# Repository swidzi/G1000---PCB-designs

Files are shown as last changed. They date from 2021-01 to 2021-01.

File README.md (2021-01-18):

# G1000 - PCB-desgins
PCB designes for G1000 Flight Sim controller STL (3d) files made by FlightSimMaker

This repository contains Eagle files for the PCB designed for G1000. All PCBs are millable on single sided clad with a 3018Pro CNC router.
Board design can be changed at anytime.
Boards are designed to be interconnected - if used separately they will probably not work.

# G1000 PFD/MFD PCB interconnection chart

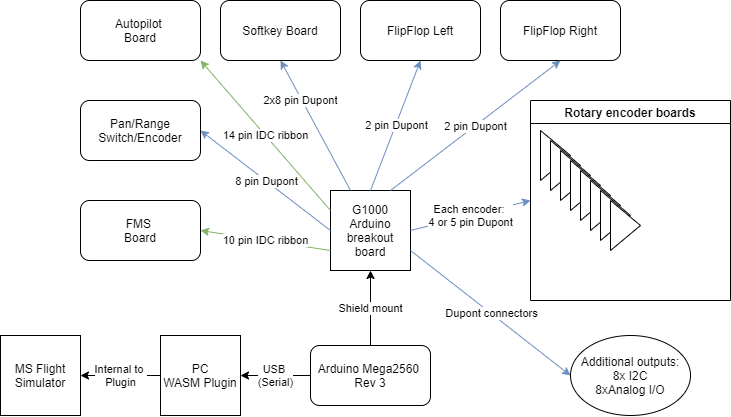
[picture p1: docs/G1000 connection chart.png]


# G1000 Audio PanelPCB interconnection chart

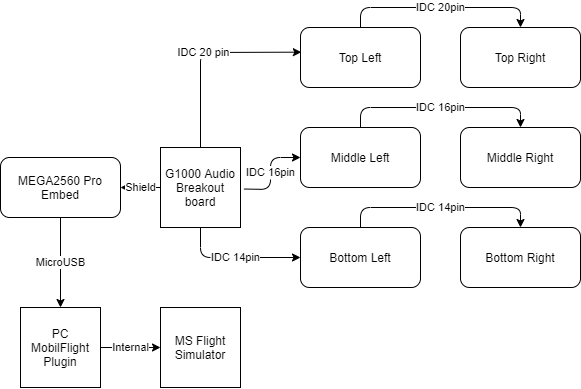
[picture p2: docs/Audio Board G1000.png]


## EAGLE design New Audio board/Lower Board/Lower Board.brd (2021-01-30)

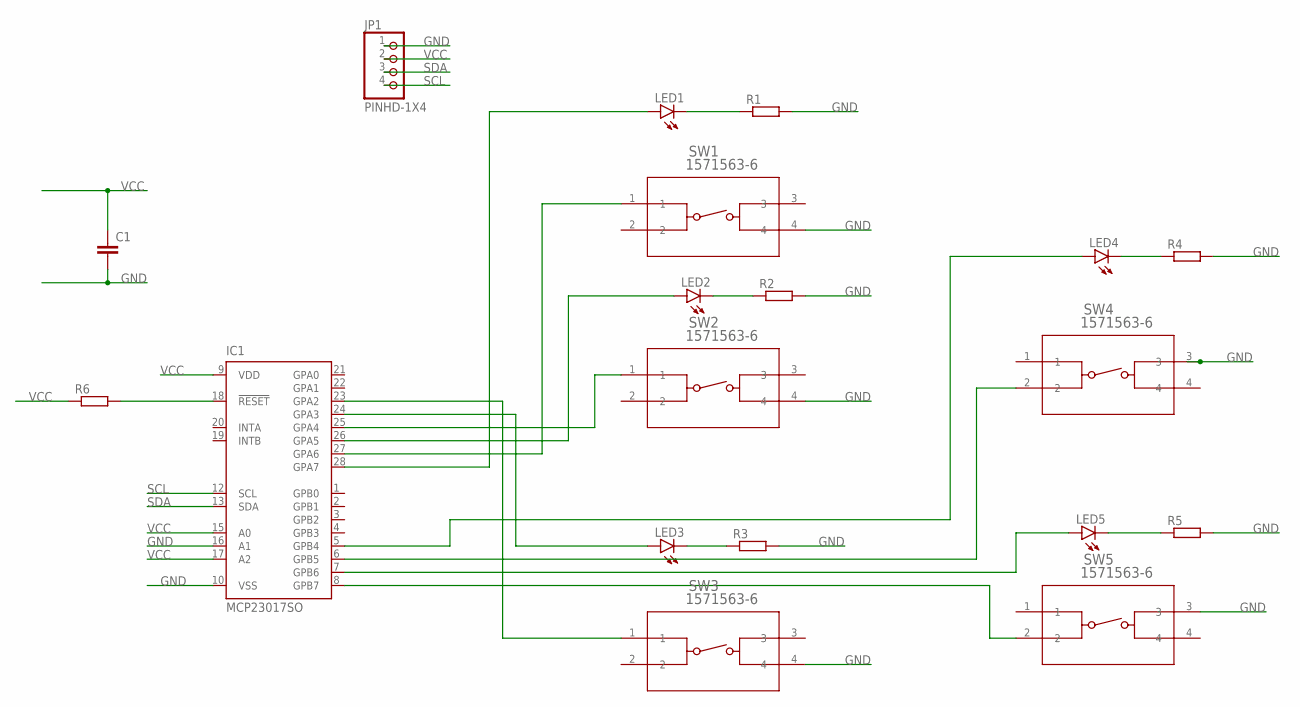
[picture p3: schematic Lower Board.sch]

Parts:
C1: C-EU025-025X050; C025-025X050
IC1: MCP23017SO; SO28W
JP1: PINHD-1X4; 1X04
LED1, LED2, LED3, LED4, LED5: LEDCHIP-LED0805; CHIP-LED0805
R1, R2, R3, R4, R5, R6: R-EU_R0805; R0805
SW1, SW2, SW3, SW4, SW5: 1571563-6; SW4_1437565-E

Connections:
GND: C1.2, IC1.10 (VSS), IC1.16 (A1), JP1.1, R1.2, R2.2, R3.2, R4.2, R5.2, SW1.4, SW2.4, SW3.4, SW4.3, SW5.3
unnamed: LED1.C, R1.1
unnamed: LED2.C, R2.1
unnamed: LED3.C, R3.1
unnamed: LED5.C, R5.1
unnamed: LED4.C, R4.1
unnamed: IC1.28 (GPA7), LED1.A
unnamed: IC1.27 (GPA6), SW1.1
unnamed: IC1.26 (GPA5), LED2.A
unnamed: IC1.25 (GPA4), SW2.1
unnamed: IC1.24 (GPA3), LED3.A
unnamed: IC1.23 (GPA2), SW3.1
unnamed: IC1.8 (GPB7), SW5.2
unnamed: IC1.18 (!RESET), R6.2
unnamed: IC1.7 (GPB6), LED5.A
unnamed: IC1.6 (GPB5), SW4.2
unnamed: IC1.5 (GPB4), LED4.A
SCL: IC1.12 (SCL), JP1.4
SDA: IC1.13 (SDA), JP1.3
VCC: C1.1, IC1.9 (VDD), IC1.15 (A0), IC1.17 (A2), JP1.2, R6.1

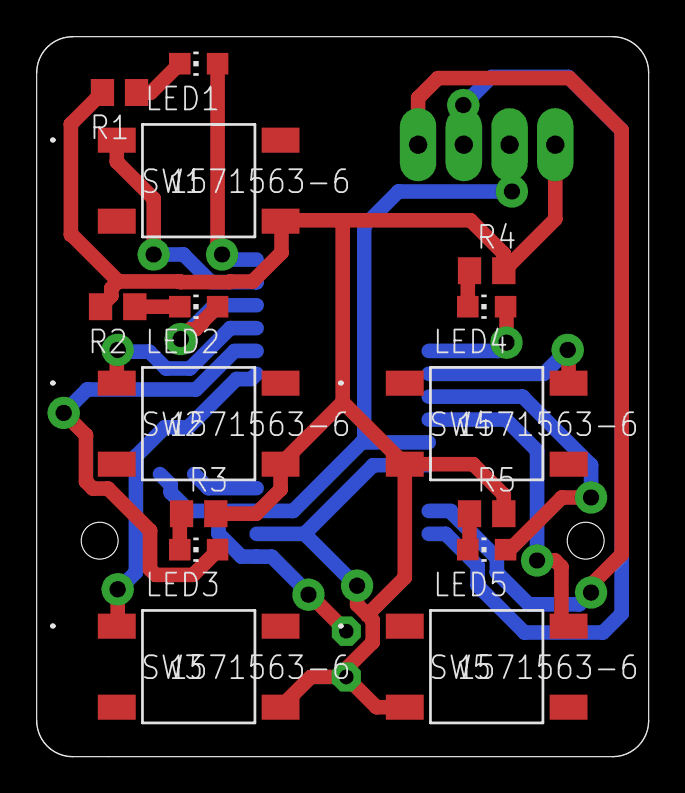
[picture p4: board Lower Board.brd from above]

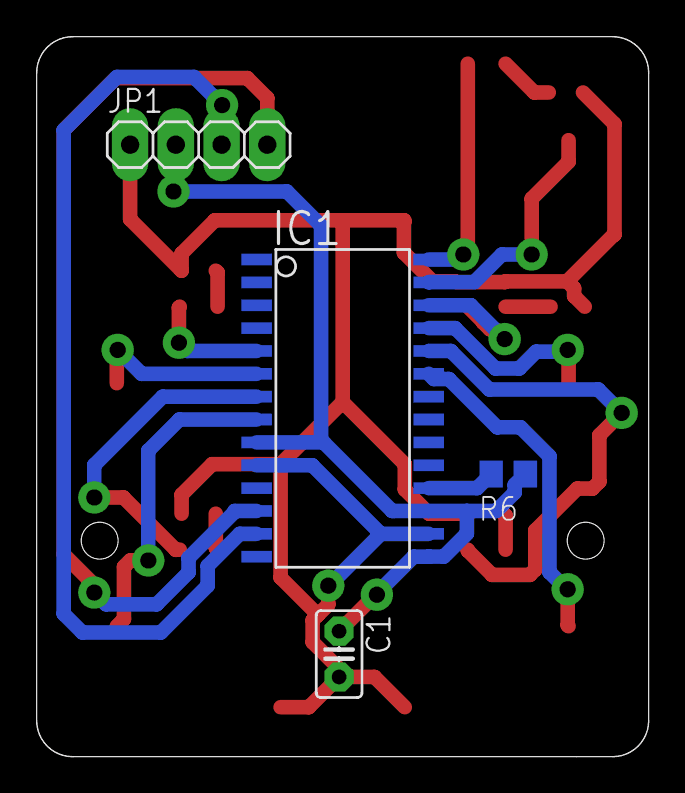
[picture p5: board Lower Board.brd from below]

Board: 2 copper layers, 34.0 x 40.0 mm, 19 parts (4 on the bottom side), 20 nets.

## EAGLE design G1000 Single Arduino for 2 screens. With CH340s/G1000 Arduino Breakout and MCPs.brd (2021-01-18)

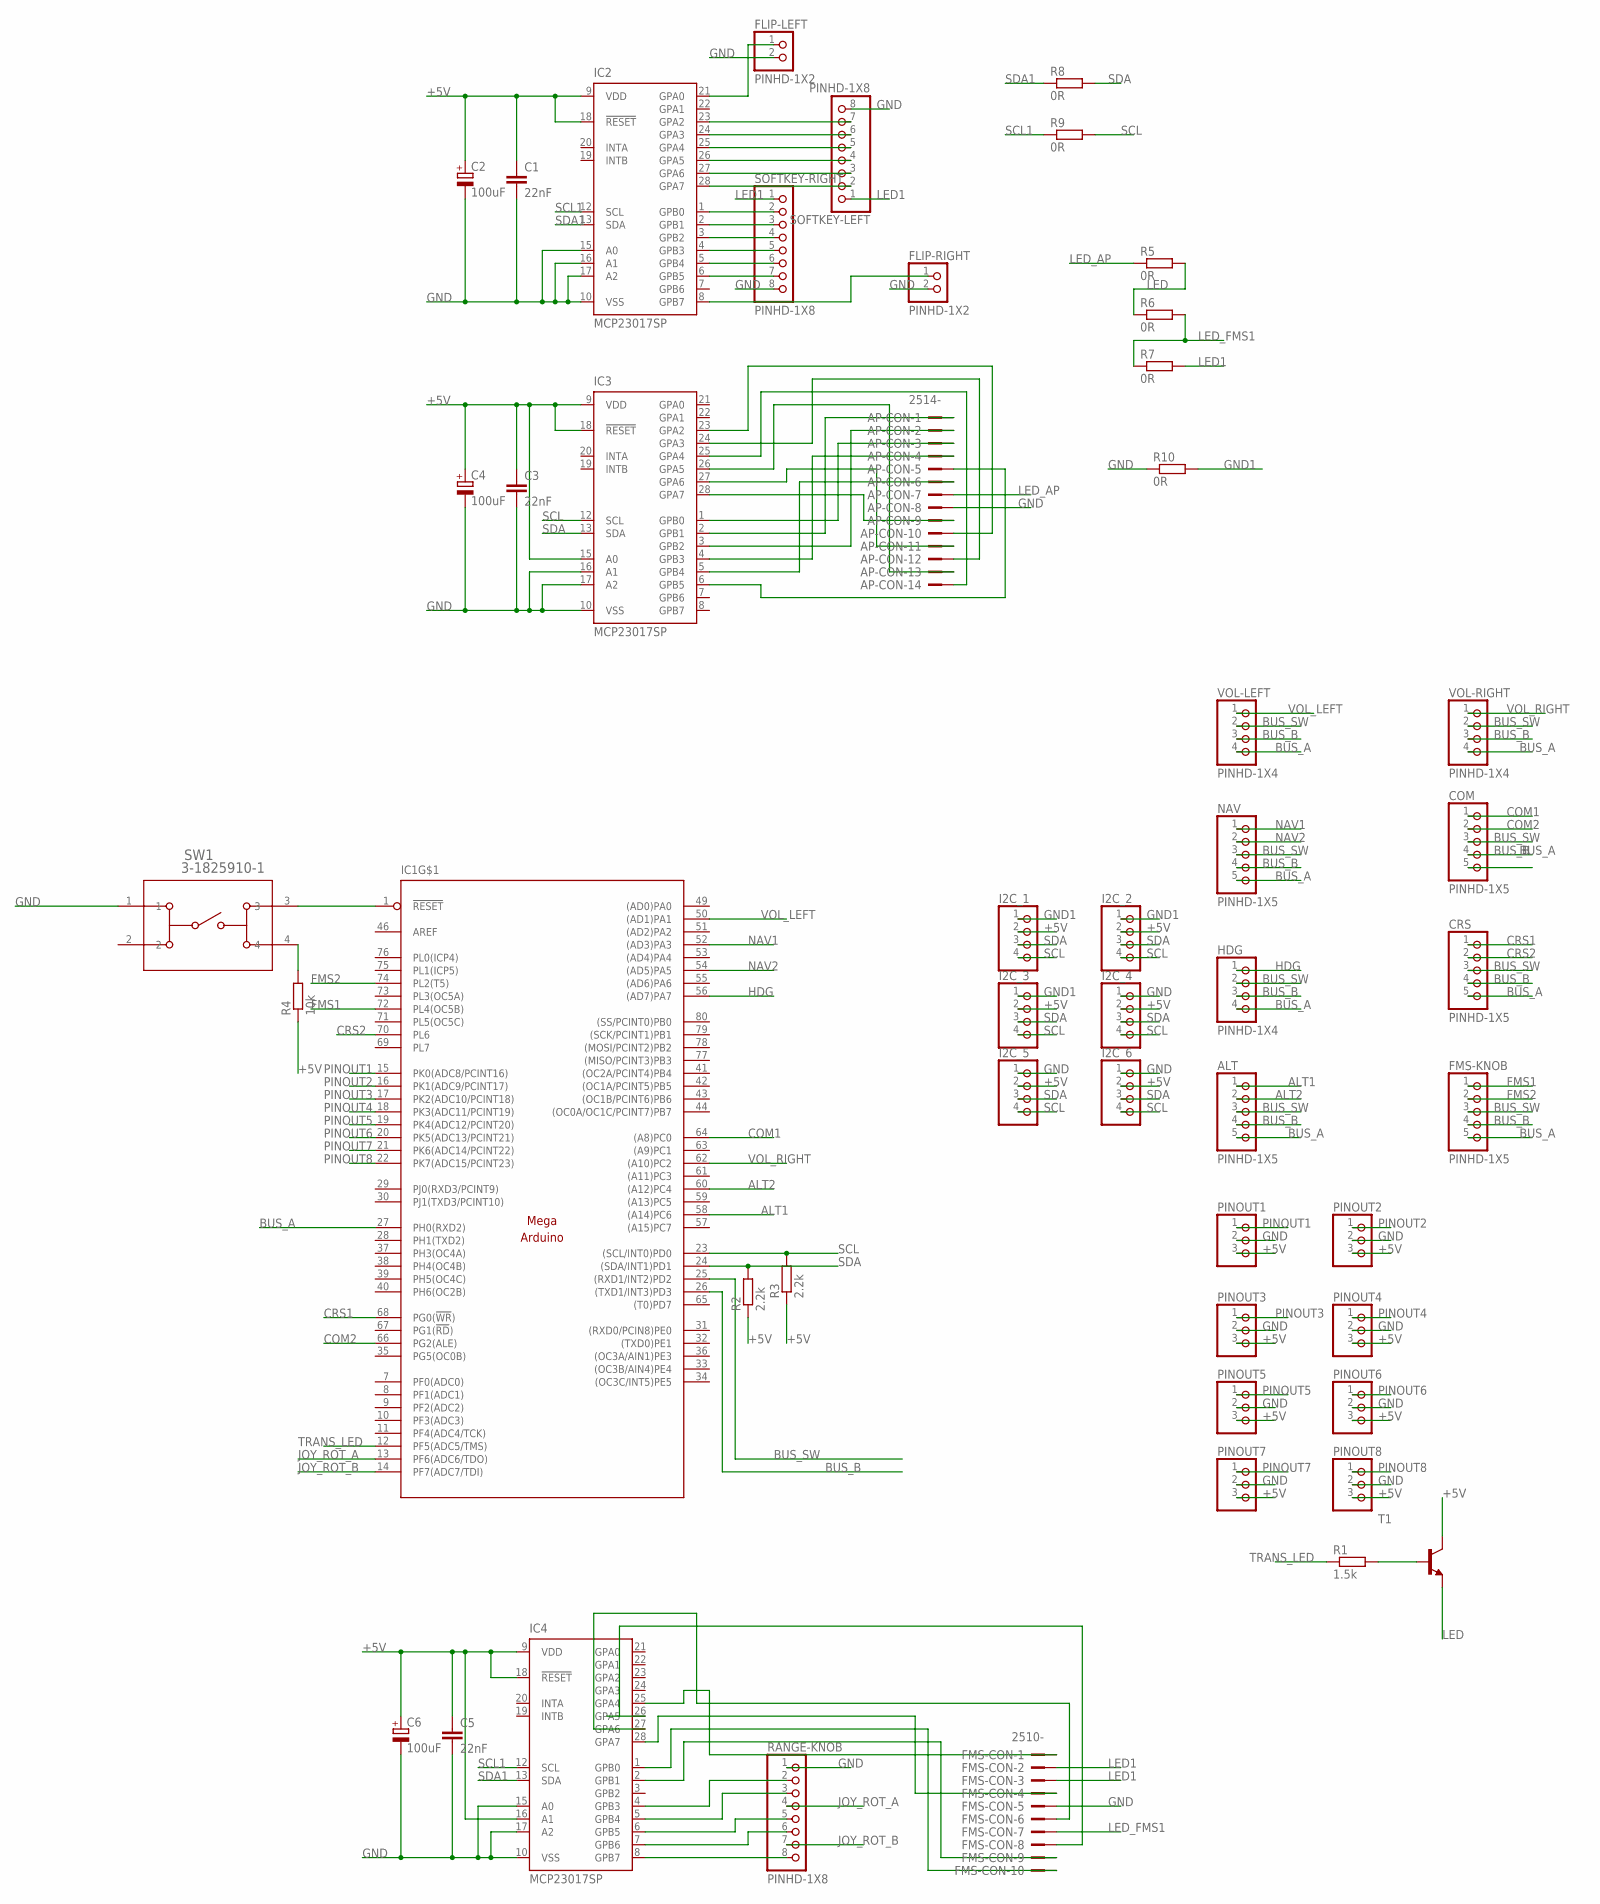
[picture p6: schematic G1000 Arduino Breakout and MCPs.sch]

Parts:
ALT: PINHD-1X5; 1X05
AP-CON: 2514-; PAK100/2500-14
C1, C3, C5: 22nF; C025-025X050
C2, C4, C6: 100uF; E2,5-6
COM: PINHD-1X5; 1X05
CRS: PINHD-1X5; 1X05
FLIP-LEFT: PINHD-1X2; 1X02
FLIP-RIGHT: PINHD-1X2; 1X02
FMS-CON: 2510-; PAK100/2500-10
FMS-KNOB: PINHD-1X5; 1X05
HDG: PINHD-1X4; 1X04
I2C_1, I2C_2, I2C_3, I2C_4, I2C_5, I2C_6: PINHD-1X4; 1X04
IC1: MEGAARDUINO_22; MEGA_ARDUINO_2
IC2, IC3, IC4: MCP23017SP; DIL28-3
NAV: PINHD-1X5; 1X05
PINOUT1, PINOUT2, PINOUT3, PINOUT4, PINOUT5, PINOUT6, PINOUT7, PINOUT8: PINHD-1X3; 1X03
R1: 1.5k; 0207/10
R2, R3: 2.2k; 0207/10
R4: 10k; 0207/10
R5, R6, R7, R8, R9, R10: 0R; 0207/10
RANGE-KNOB: PINHD-1X8; 1X08
SOFTKEY-LEFT: PINHD-1X8; 1X08
SOFTKEY-RIGHT: PINHD-1X8; 1X08
SW1: 3-1825910-1; SW4_1825910-H
T1: 2N2222-NPN-TO92-EBC; TO92-EBC
VOL-LEFT: PINHD-1X4; 1X04
VOL-RIGHT: PINHD-1X4; 1X04

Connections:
+3V3: IC1.2 (+3V3)
+5V: C1.1, C2.+, C3.1, C4.+, C5.1, C6.+, I2C_1.2, I2C_2.2, I2C_3.2, I2C_4.2, I2C_5.2, I2C_6.2, IC1.3 (+5V), IC1.47 (+5V), IC1.48 (+5V), IC2.9 (VDD), IC2.18 (!RESET), IC3.9 (VDD), IC3.15 (A0), IC3.18 (!RESET), IC4.9 (VDD), IC4.16 (A1), IC4.18 (!RESET), PINOUT1.3, PINOUT2.3, PINOUT3.3, PINOUT4.3, PINOUT5.3, PINOUT6.3, PINOUT7.3, PINOUT8.3, R2.1, R3.1, R4.1, T1.C
+VIN: IC1.6 (+VIN)
ALT1: ALT.1, IC1.58 ((A14)PC6)
ALT2: ALT.2, IC1.60 ((A12)PC4)
BUS_A: ALT.5, COM.5, CRS.5, FMS-KNOB.5, HDG.4, IC1.27 (PH0(RXD2)), NAV.5, VOL-LEFT.4, VOL-RIGHT.4
BUS_B: ALT.4, COM.4, CRS.4, FMS-KNOB.4, HDG.3, IC1.26 ((TXD1/INT3)PD3), NAV.4, VOL-LEFT.3, VOL-RIGHT.3
BUS_SW: ALT.3, COM.3, CRS.3, FMS-KNOB.3, HDG.2, IC1.25 ((RXD1/INT2)PD2), NAV.3, VOL-LEFT.2, VOL-RIGHT.2
COM1: COM.1, IC1.64 ((A8)PC0)
COM2: COM.2, IC1.66 (PG2(ALE))
CRS1: CRS.1, IC1.68 (PG0(!WR!))
CRS2: CRS.2, IC1.70 (PL6)
FMS1: FMS-KNOB.1, IC1.72 (PL4(OC5B))
FMS2: FMS-KNOB.2, IC1.74 (PL2(T5))
GND: AP-CON.8, C1.2, C2.-, C3.2, C4.-, C5.2, C6.-, FLIP-LEFT.2, FLIP-RIGHT.2, FMS-CON.5, I2C_4.1, I2C_5.1, I2C_6.1, IC1.4 (GND), IC1.5 (GND), IC1.45 (GND), IC1.81 (GND), IC1.82 (GND), IC2.10 (VSS), IC2.15 (A0), IC2.16 (A1), IC2.17 (A2), IC3.10 (VSS), IC3.16 (A1), IC3.17 (A2), IC4.10 (VSS), IC4.15 (A0), IC4.17 (A2), PINOUT1.2, PINOUT2.2, PINOUT3.2, PINOUT4.2, PINOUT5.2, PINOUT6.2, PINOUT7.2, PINOUT8.2, R10.1, RANGE-KNOB.1, SOFTKEY-LEFT.8, SOFTKEY-RIGHT.8, SW1.1
GND1: I2C_1.1, I2C_2.1, I2C_3.1, R10.2
HDG: HDG.1, IC1.56 ((AD7)PA7)
JOY_ROT_A: IC1.13 (PF6(ADC6/TDO)), RANGE-KNOB.4
JOY_ROT_B: IC1.14 (PF7(ADC7/TDI)), RANGE-KNOB.7
LED: R5.2, R6.1, T1.E
LED1: FMS-CON.2, FMS-CON.3, R7.2, SOFTKEY-LEFT.1, SOFTKEY-RIGHT.1
LED_AP: AP-CON.7, R5.1
LED_FMS1: FMS-CON.7, R6.2, R7.1
unnamed: R1.2, T1.B
unnamed: IC2.1 (GPB0), SOFTKEY-RIGHT.2
unnamed: IC2.2 (GPB1), SOFTKEY-RIGHT.3
unnamed: IC2.3 (GPB2), SOFTKEY-RIGHT.4
unnamed: IC2.4 (GPB3), SOFTKEY-RIGHT.5
unnamed: IC2.5 (GPB4), SOFTKEY-RIGHT.6
unnamed: IC2.6 (GPB5), SOFTKEY-RIGHT.7
unnamed: IC2.28 (GPA7), SOFTKEY-LEFT.2
unnamed: IC2.27 (GPA6), SOFTKEY-LEFT.3
unnamed: IC2.26 (GPA5), SOFTKEY-LEFT.4
unnamed: IC2.25 (GPA4), SOFTKEY-LEFT.5
unnamed: IC2.24 (GPA3), SOFTKEY-LEFT.6
unnamed: IC2.23 (GPA2), SOFTKEY-LEFT.7
unnamed: FLIP-LEFT.1, IC2.21 (GPA0)
unnamed: FLIP-RIGHT.1, IC2.8 (GPB7)
unnamed: R4.2, SW1.4
unnamed: AP-CON.3, IC3.1 (GPB0)
unnamed: IC1.1 (!RESET), SW1.3
unnamed: AP-CON.1, IC3.2 (GPB1)
unnamed: AP-CON.2, IC3.3 (GPB2)
unnamed: AP-CON.4, IC3.4 (GPB3)
unnamed: AP-CON.6, IC3.5 (GPB4)
unnamed: AP-CON.9, IC3.28 (GPA7)
unnamed: AP-CON.11, IC3.27 (GPA6)
unnamed: AP-CON.13, IC3.26 (GPA5)
unnamed: AP-CON.14, IC3.25 (GPA4)
unnamed: AP-CON.12, IC3.24 (GPA3)
unnamed: AP-CON.10, IC3.23 (GPA2)
unnamed: AP-CON.5, IC3.6 (GPB5)
unnamed: IC4.8 (GPB7), RANGE-KNOB.8
unnamed: IC4.7 (GPB6), RANGE-KNOB.6
unnamed: IC4.6 (GPB5), RANGE-KNOB.5
unnamed: IC4.5 (GPB4), RANGE-KNOB.3
unnamed: IC4.4 (GPB3), RANGE-KNOB.2
unnamed: FMS-CON.1, IC4.25 (GPA4)
unnamed: FMS-CON.9, IC4.2 (GPB1)
unnamed: FMS-CON.10, IC4.1 (GPB0)
unnamed: FMS-CON.4, IC4.28 (GPA7)
unnamed: FMS-CON.6, IC4.27 (GPA6)
unnamed: FMS-CON.8, IC4.26 (GPA5)
NAV1: IC1.52 ((AD3)PA3), NAV.1
NAV2: IC1.54 ((AD5)PA5), NAV.2
PINOUT1: IC1.15 (PK0(ADC8/PCINT16)), PINOUT1.1
PINOUT2: IC1.16 (PK1(ADC9/PCINT17)), PINOUT2.1
PINOUT3: IC1.17 (PK2(ADC10/PCINT18)), PINOUT3.1
PINOUT4: IC1.18 (PK3(ADC11/PCINT19)), PINOUT4.1
PINOUT5: IC1.19 (PK4(ADC12/PCINT20)), PINOUT5.1
PINOUT6: IC1.20 (PK5(ADC13/PCINT21)), PINOUT6.1
PINOUT7: IC1.21 (PK6(ADC14/PCINT22)), PINOUT7.1
PINOUT8: IC1.22 (PK7(ADC15/PCINT23)), PINOUT8.1
SCL: I2C_1.4, I2C_2.4, I2C_3.4, I2C_4.4, I2C_5.4, I2C_6.4, IC1.23 ((SCL/INT0)PD0), IC3.12 (SCL), R3.2, R9.2
SCL1: IC2.12 (SCL), IC4.12 (SCL), R9.1
SDA: I2C_1.3, I2C_2.3, I2C_3.3, I2C_4.3, I2C_5.3, I2C_6.3, IC1.24 ((SDA/INT1)PD1), IC3.13 (SDA), R2.2, R8.2
SDA1: IC2.13 (SDA), IC4.13 (SDA), R8.1
TRANS_LED: IC1.12 (PF5(ADC5/TMS)), R1.1
VOL_LEFT: IC1.50 ((AD1)PA1), VOL-LEFT.1
VOL_RIGHT: IC1.62 ((A10)PC2), VOL-RIGHT.1

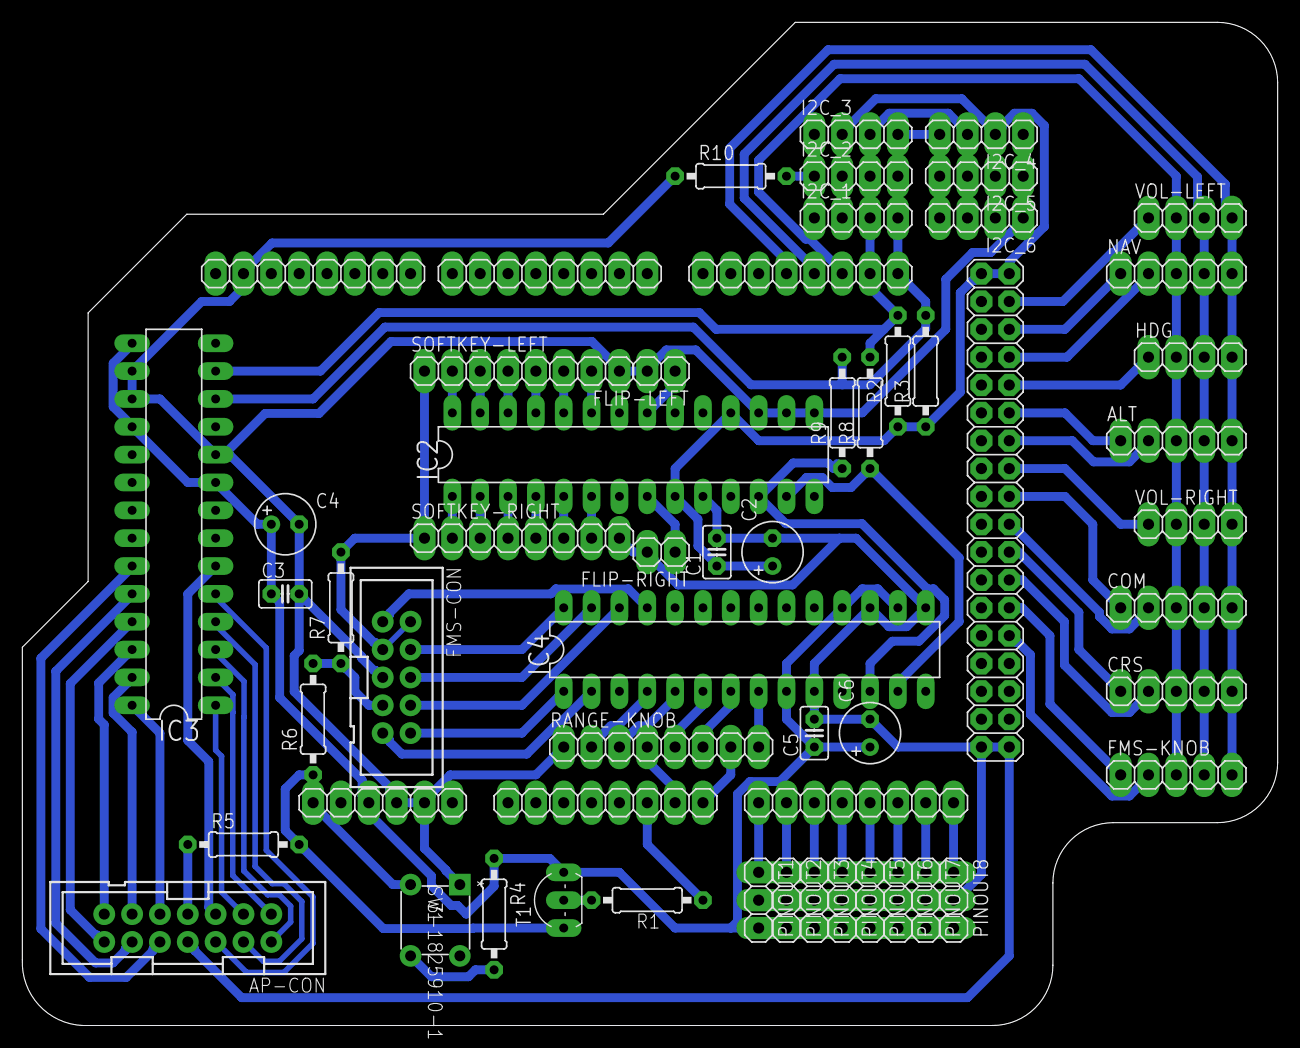
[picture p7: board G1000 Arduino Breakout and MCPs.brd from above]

Board: 2 copper layers, 114.5 x 91.5 mm, 51 parts (0 on the bottom side), 78 nets.

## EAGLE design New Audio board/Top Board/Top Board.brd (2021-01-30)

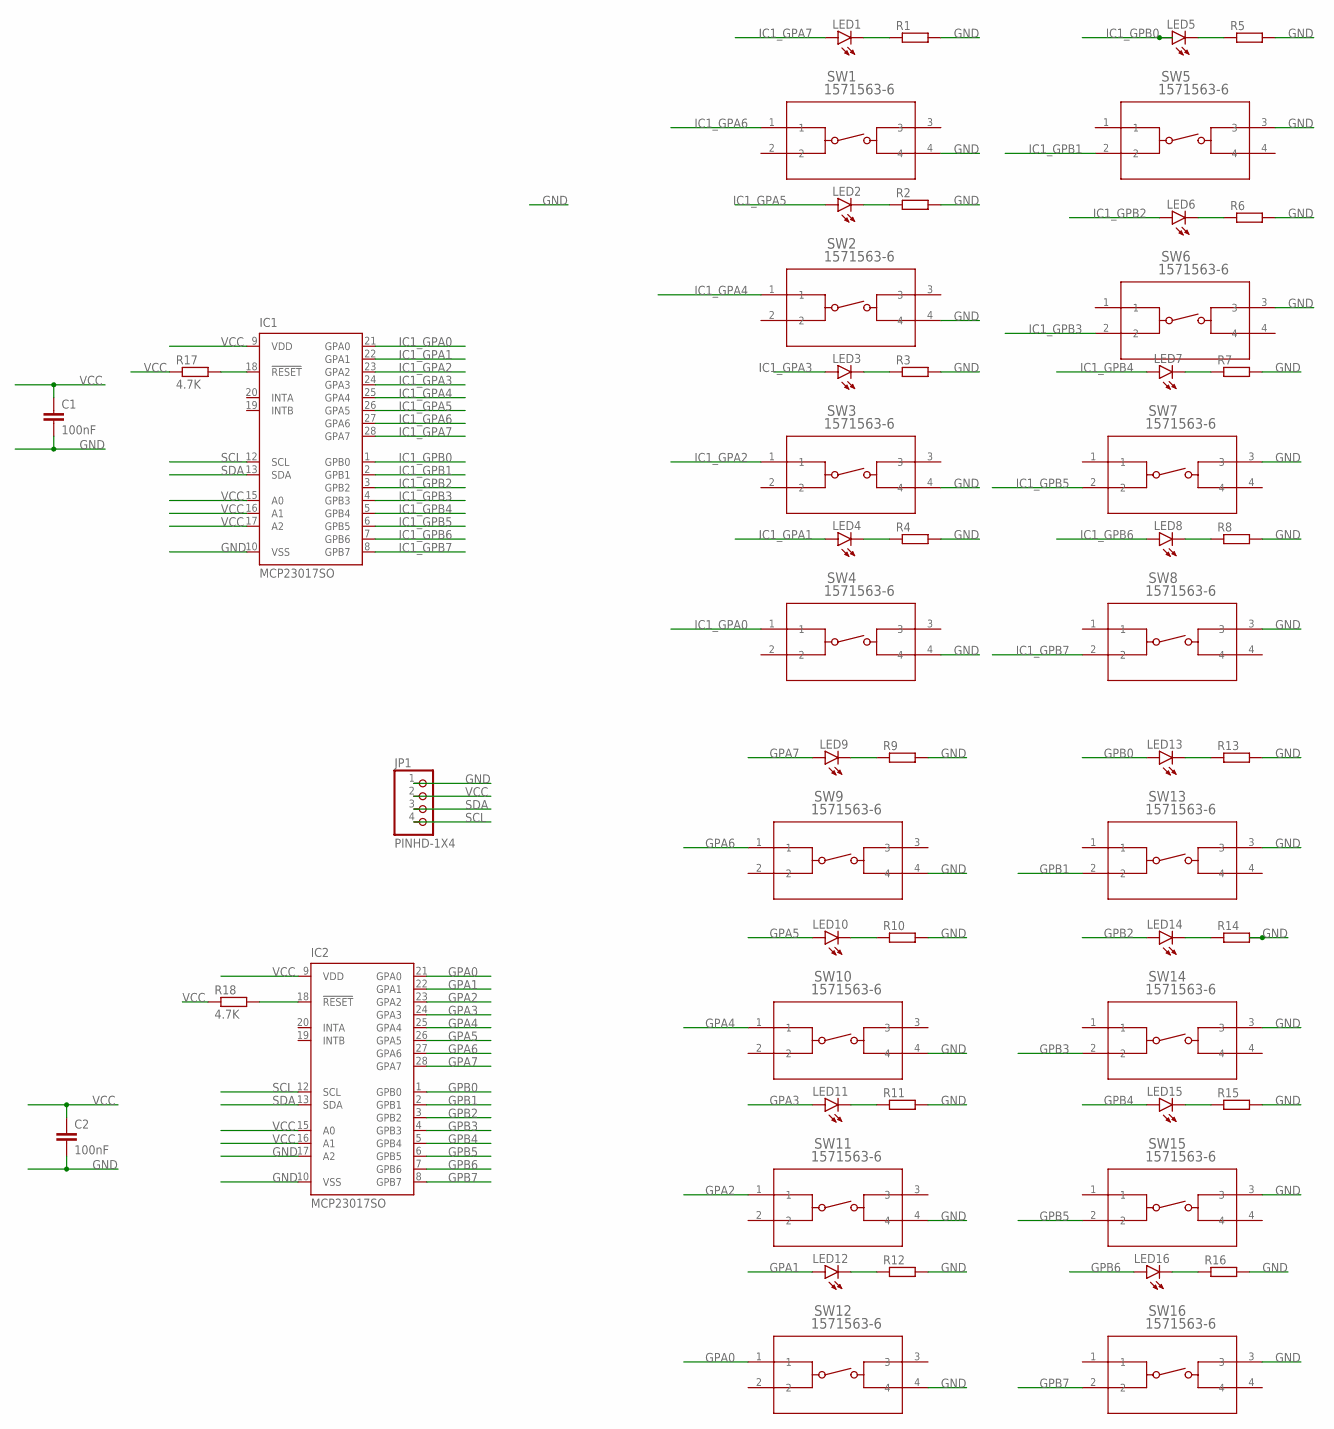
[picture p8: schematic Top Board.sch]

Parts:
C1, C2: 100nF; C025-025X050
IC1, IC2: MCP23017SO; SO28W
JP1: PINHD-1X4; 1X04
LED1, LED2, LED3, LED4, LED5, LED6, LED7, LED8, LED9, LED10, LED11, LED12, LED13, LED14, LED15, LED16: LEDCHIP-LED0805; CHIP-LED0805
R1, R2, R3, R4, R5, R6, R7, R8, R9, R10, R11, R12, R13, R14, R15, R16: R-EU_R0805; R0805
R17, R18: 4.7K; R0805
SW1, SW2, SW3, SW4, SW5, SW6, SW7, SW8, SW9, SW10, SW11, SW12, SW13, SW14, SW15, SW16: 1571563-6; SW4_1437565-E

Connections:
GND: C1.2, C2.2, IC1.10 (VSS), IC2.10 (VSS), IC2.17 (A2), JP1.1, R1.2, R2.2, R3.2, R4.2, R5.2, R6.2, R7.2, R8.2, R9.2, R10.2, R11.2, R12.2, R13.2, R14.2, R15.2, R16.2, SW1.4, SW2.4, SW3.4, SW4.4, SW5.3, SW6.3, SW7.3, SW8.3, SW9.4, SW10.4, SW11.4, SW12.4, SW13.3, SW14.3, SW15.3, SW16.3
GPA0: IC2.21 (GPA0), SW12.1
GPA1: IC2.22 (GPA1), LED12.A
GPA2: IC2.23 (GPA2), SW11.1
GPA3: IC2.24 (GPA3), LED11.A
GPA4: IC2.25 (GPA4), SW10.1
GPA5: IC2.26 (GPA5), LED10.A
GPA6: IC2.27 (GPA6), SW9.1
GPA7: IC2.28 (GPA7), LED9.A
GPB0: IC2.1 (GPB0), LED13.A
GPB1: IC2.2 (GPB1), SW13.2
GPB2: IC2.3 (GPB2), LED14.A
GPB3: IC2.4 (GPB3), SW14.2
GPB4: IC2.5 (GPB4), LED15.A
GPB5: IC2.6 (GPB5), SW15.2
GPB6: IC2.7 (GPB6), LED16.A
GPB7: IC2.8 (GPB7), SW16.2
IC1_GPA0: IC1.21 (GPA0), SW4.1
IC1_GPA1: IC1.22 (GPA1), LED4.A
IC1_GPA2: IC1.23 (GPA2), SW3.1
IC1_GPA3: IC1.24 (GPA3), LED3.A
IC1_GPA4: IC1.25 (GPA4), SW2.1
IC1_GPA5: IC1.26 (GPA5), LED2.A
IC1_GPA6: IC1.27 (GPA6), SW1.1
IC1_GPA7: IC1.28 (GPA7), LED1.A
IC1_GPB0: IC1.1 (GPB0), LED5.A
IC1_GPB1: IC1.2 (GPB1), SW5.2
IC1_GPB2: IC1.3 (GPB2), LED6.A
IC1_GPB3: IC1.4 (GPB3), SW6.2
IC1_GPB4: IC1.5 (GPB4), LED7.A
IC1_GPB5: IC1.6 (GPB5), SW7.2
IC1_GPB6: IC1.7 (GPB6), LED8.A
IC1_GPB7: IC1.8 (GPB7), SW8.2
unnamed: LED1.C, R1.1
unnamed: LED2.C, R2.1
unnamed: LED3.C, R3.1
unnamed: LED4.C, R4.1
unnamed: LED5.C, R5.1
unnamed: LED6.C, R6.1
unnamed: LED7.C, R7.1
unnamed: LED8.C, R8.1
unnamed: LED9.C, R9.1
unnamed: LED10.C, R10.1
unnamed: LED11.C, R11.1
unnamed: LED12.C, R12.1
unnamed: LED13.C, R13.1
unnamed: LED14.C, R14.1
unnamed: LED15.C, R15.1
unnamed: LED16.C, R16.1
unnamed: IC2.18 (!RESET), R18.2
unnamed: IC1.18 (!RESET), R17.2
SCL: IC1.12 (SCL), IC2.12 (SCL), JP1.4
SDA: IC1.13 (SDA), IC2.13 (SDA), JP1.3
VCC: C1.1, C2.1, IC1.9 (VDD), IC1.15 (A0), IC1.16 (A1), IC1.17 (A2), IC2.9 (VDD), IC2.15 (A0), IC2.16 (A1), JP1.2, R17.1, R18.1

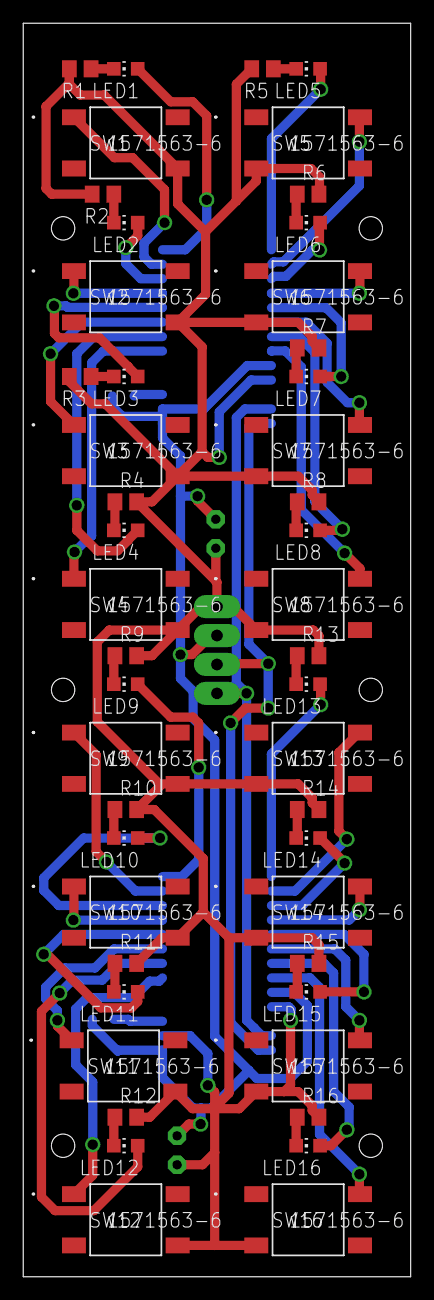
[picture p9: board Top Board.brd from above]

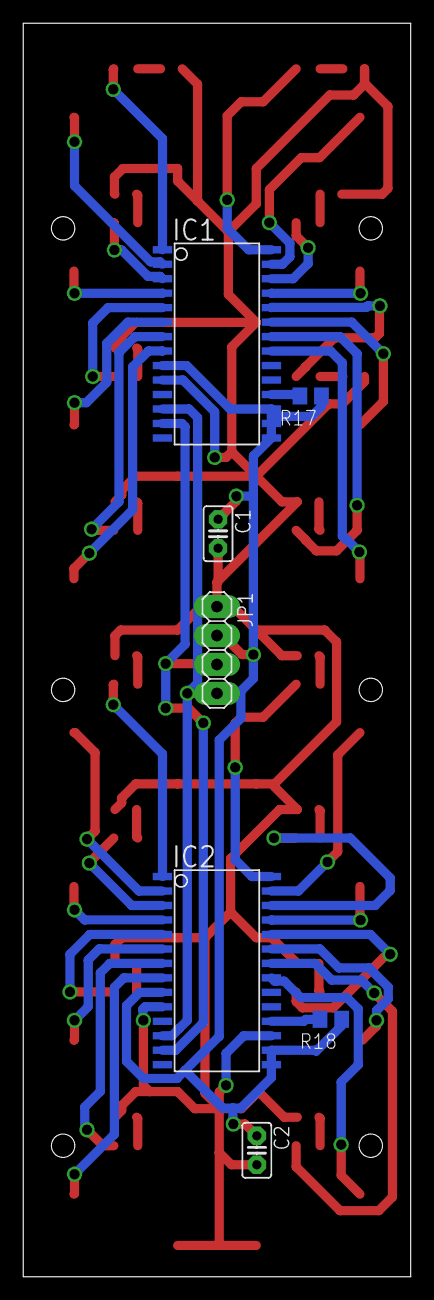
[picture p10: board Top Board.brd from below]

Board: 2 copper layers, 34.0 x 110.0 mm, 55 parts (7 on the bottom side), 54 nets.

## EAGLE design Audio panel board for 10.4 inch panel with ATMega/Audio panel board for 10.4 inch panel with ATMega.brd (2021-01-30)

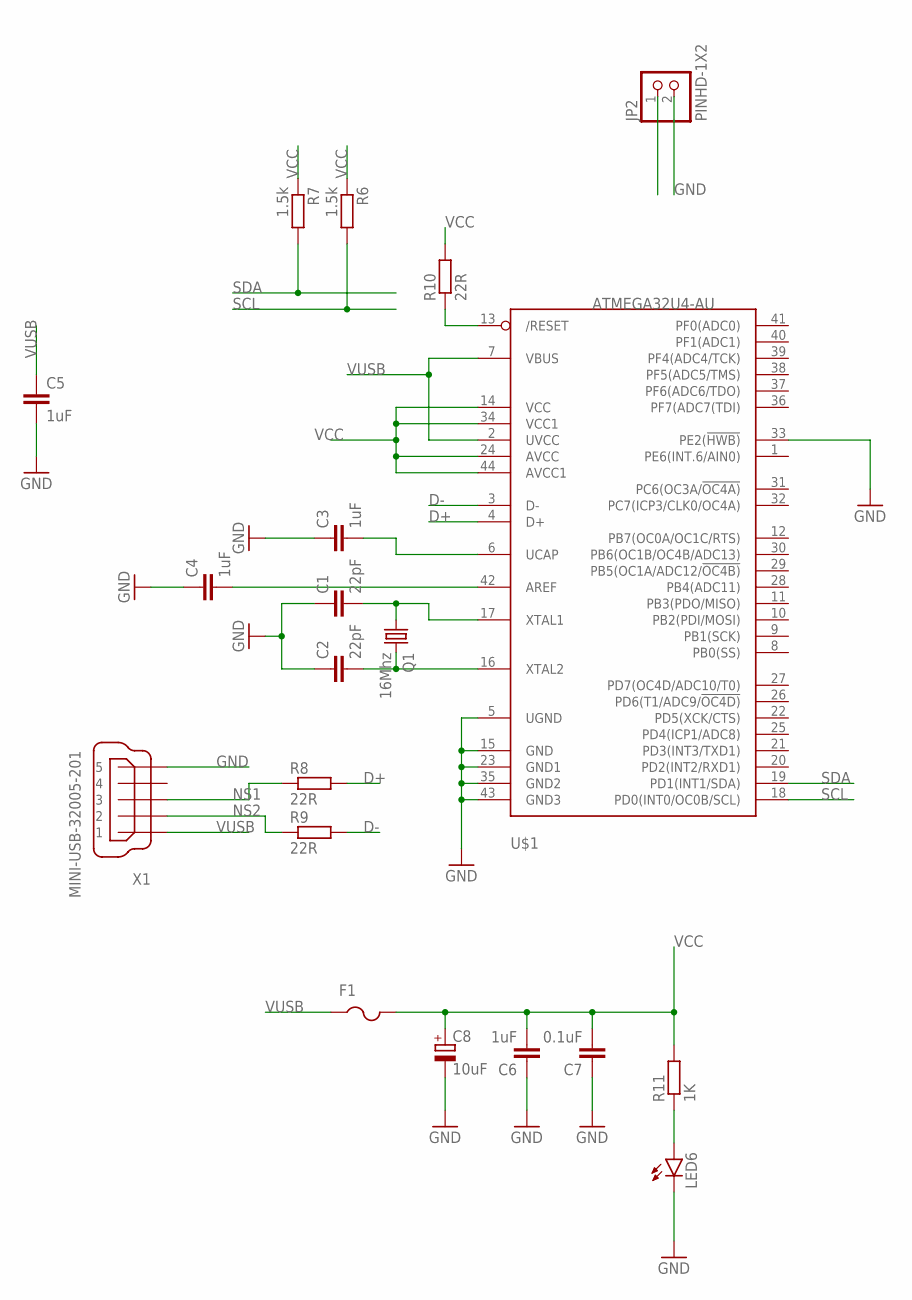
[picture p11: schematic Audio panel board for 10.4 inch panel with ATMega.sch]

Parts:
C1, C2: 22pF; C025-025X050
C3, C4, C5, C6: 1uF; C025-025X050
C7: 0.1uF; C025-025X050
C8: 10uF; E2,5-7
F1: PTCFUSE-1206; R1206
JP2: PINHD-1X2; 1X02
LED6: LEDCHIP-LED0805; CHIP-LED0805
Q1: 16Mhz; HC49/S
R6, R7: 1.5k; R0805
R8, R9, R10: 22R; R0805
R11: 1K; R0805
U$1: ATMEGA32U4-AU; TQFP44
X1: MINI-USB-32005-201; 32005-201

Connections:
D+: R8.2, U$1.4 (D+)
D-: R9.2, U$1.3 (D-)
GND: C1.1, C2.1, C3.1, C4.1, C5.2, C6.1, C7.1, C8.-, JP2.2, LED6.C, U$1.5 (UGND), U$1.15 (GND), U$1.23 (GND1), U$1.33 (PE2(!HWB)), U$1.35 (GND2), U$1.43 (GND3), X1.5
unnamed: C4.2, U$1.42 (AREF)
unnamed: C2.2, Q1.2, U$1.16 (XTAL2)
unnamed: C1.2, Q1.1, U$1.17 (XTAL1)
unnamed: C3.2, U$1.6 (UCAP)
unnamed: R10.1, U$1.13 (/RESET)
unnamed: LED6.A, R11.1
NS1: R8.1, X1.3
NS2: R9.1, X1.2
SCL: R6.2, U$1.18 (PD0(INT0/OC0B/SCL))
SDA: R7.2, U$1.19 (PD1(INT1/SDA))
VCC: C6.2, C7.2, C8.+, F1.2, R6.1, R7.1, R10.2, R11.2, U$1.14 (VCC), U$1.24 (AVCC), U$1.34 (VCC1), U$1.44 (AVCC1)
VUSB: C5.1, F1.1, U$1.2 (UVCC), U$1.7 (VBUS), X1.1

Board: 2 copper layers, 20 parts (1 on the bottom side), 15 nets, no tracks yet.

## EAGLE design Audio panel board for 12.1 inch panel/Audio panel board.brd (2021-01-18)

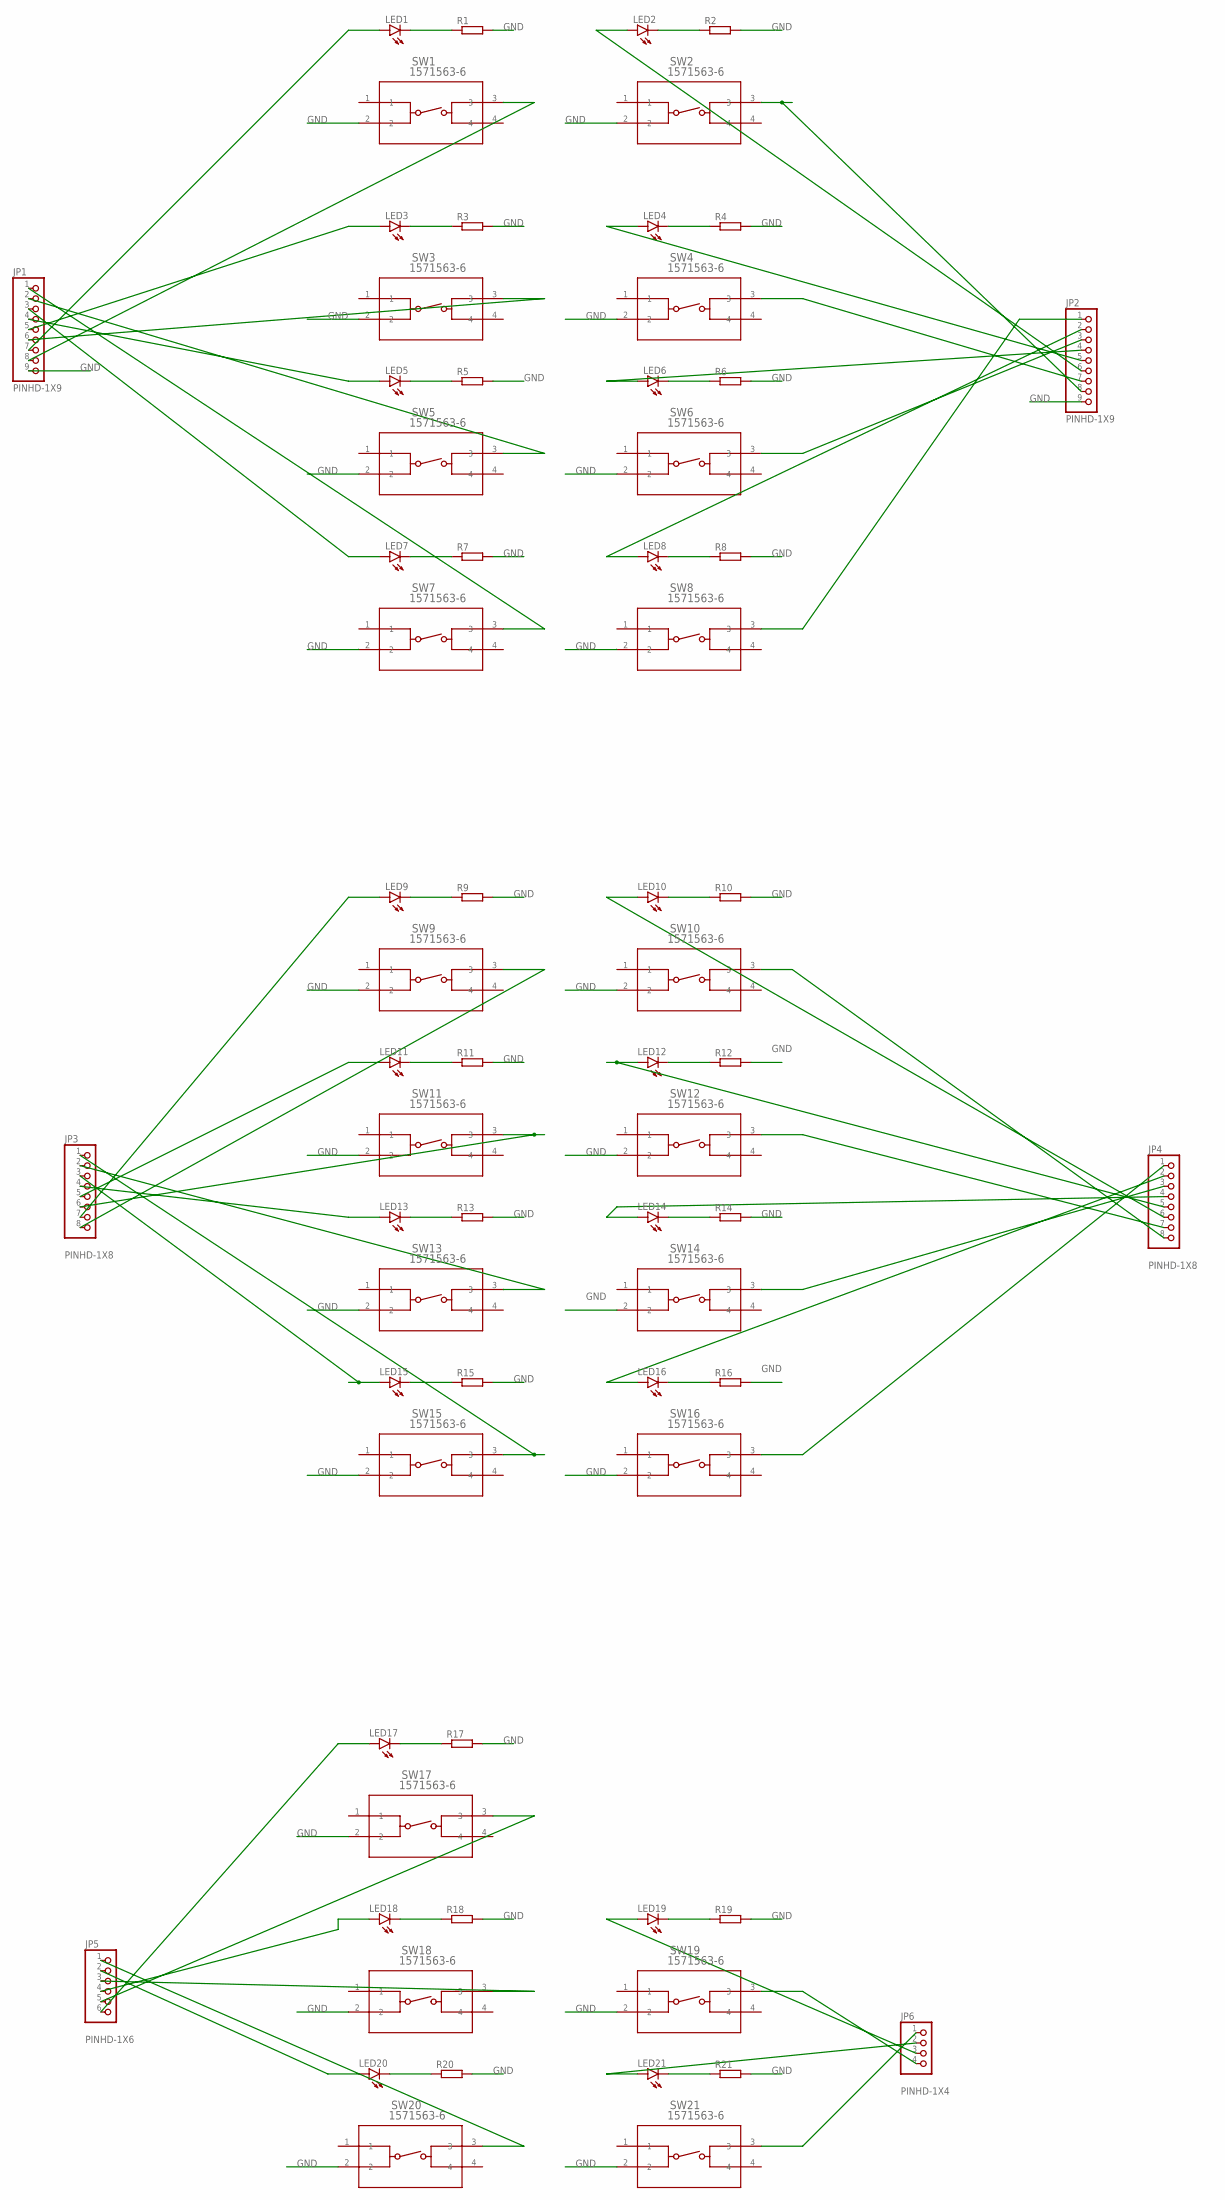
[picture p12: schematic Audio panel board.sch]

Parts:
JP1, JP2: PINHD-1X9; 1X09
JP3, JP4: PINHD-1X8; 1X08
JP5: PINHD-1X6; 1X06
JP6: PINHD-1X4; 1X04
LED1, LED2, LED3, LED4, LED5, LED6, LED7, LED8, LED9, LED10, LED11, LED12, LED13, LED14, LED15, LED16, LED17, LED18, LED19, LED20, LED21: LEDCHIP-LED0805; CHIP-LED0805
R1, R2, R3, R4, R5, R6, R7, R8, R9, R10, R11, R12, R13, R14, R15, R16, R17, R18, R19, R20, R21: R-EU_R1206; R1206
SW1, SW2, SW3, SW4, SW5, SW6, SW7, SW8, SW9, SW10, SW11, SW12, SW13, SW14, SW15, SW16, SW17, SW18, SW19, SW20, SW21: 1571563-6; SW4_1437565-E

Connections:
GND: JP1.9, JP2.9, R1.2, R2.2, R3.2, R4.2, R5.2, R6.2, R7.2, R8.2, R9.2, R10.2, R11.2, R12.2, R13.2, R14.2, R15.2, R16.2, R17.2, R18.2, R19.2, R20.2, R21.2, SW1.2, SW2.2, SW3.2, SW4.2, SW5.2, SW6.2, SW7.2, SW8.2, SW9.2, SW10.2, SW11.2, SW12.2, SW13.2, SW14.2, SW15.2, SW16.2, SW17.2, SW18.2, SW19.2, SW20.2, SW21.2
unnamed: JP2.1, SW8.3
unnamed: JP4.8, SW10.3
unnamed: JP5.4, LED18.A
unnamed: LED1.C, R1.1
unnamed: LED2.C, R2.1
unnamed: LED3.C, R3.1
unnamed: JP1.7, LED1.A
unnamed: JP1.5, LED3.A
unnamed: JP2.6, LED2.A
unnamed: JP2.8, SW2.3
unnamed: JP1.8, SW1.3
unnamed: JP1.6, SW3.3
unnamed: LED4.C, R4.1
unnamed: JP2.5, LED4.A
unnamed: JP2.7, SW4.3
unnamed: LED5.C, R5.1
unnamed: JP1.4, LED5.A
unnamed: JP1.2, SW5.3
unnamed: LED6.C, R6.1
unnamed: JP2.4, LED6.A
unnamed: JP2.3, SW6.3
unnamed: LED7.C, R7.1
unnamed: JP1.3, LED7.A
unnamed: JP1.1, SW7.3
unnamed: LED8.C, R8.1
unnamed: JP2.2, LED8.A
unnamed: LED9.C, R9.1
unnamed: JP3.7, LED9.A
unnamed: JP3.8, SW9.3
unnamed: LED10.C, R10.1
unnamed: JP4.6, LED10.A
unnamed: LED11.C, R11.1
unnamed: JP3.5, LED11.A
unnamed: JP3.6, SW11.3
unnamed: LED12.C, R12.1
unnamed: JP4.5, LED12.A
unnamed: JP4.7, SW12.3
unnamed: LED13.C, R13.1
unnamed: JP3.4, LED13.A
unnamed: JP3.2, SW13.3
unnamed: LED14.C, R14.1
unnamed: JP4.4, LED14.A
unnamed: JP4.3, SW14.3
unnamed: LED15.C, R15.1
unnamed: JP3.3, LED15.A
unnamed: JP3.1, SW15.3
unnamed: LED16.C, R16.1
unnamed: JP4.2, LED16.A
unnamed: JP4.1, SW16.3
unnamed: LED17.C, R17.1
unnamed: JP5.6, LED17.A
unnamed: JP5.5, SW17.3
unnamed: LED18.C, R18.1
unnamed: JP5.3, SW18.3
unnamed: LED19.C, R19.1
unnamed: JP6.3, LED19.A
unnamed: JP6.4, SW19.3
unnamed: LED20.C, R20.1
unnamed: JP5.2, LED20.A
unnamed: JP5.1, SW20.3
unnamed: LED21.C, R21.1
unnamed: JP6.2, LED21.A
unnamed: JP6.1, SW21.3

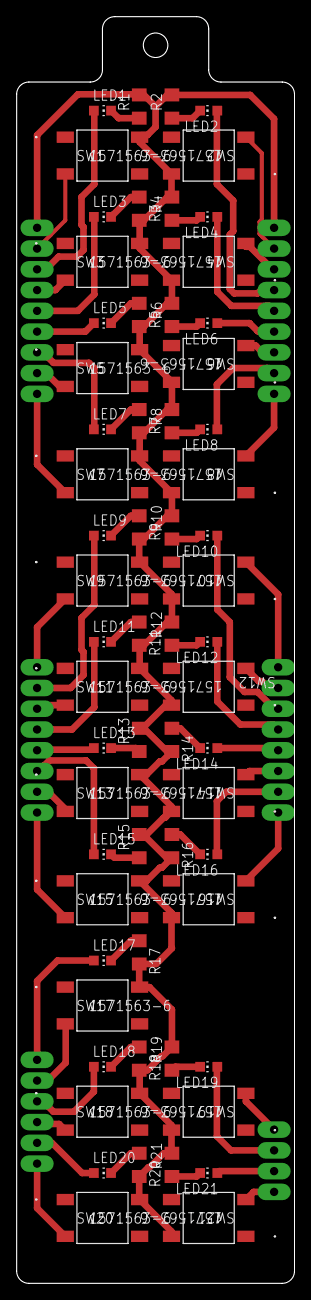
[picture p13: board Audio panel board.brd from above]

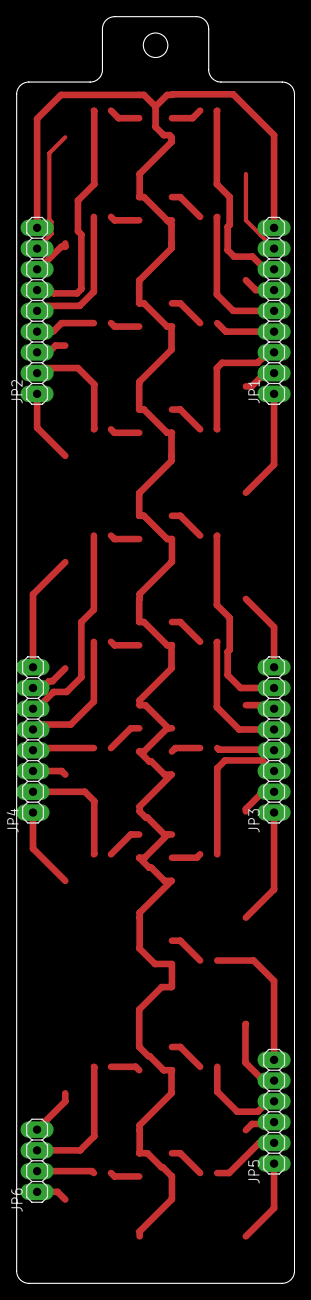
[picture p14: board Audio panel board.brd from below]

Board: 2 copper layers, 34.0 x 155.0 mm, 69 parts (6 on the bottom side), 64 nets.

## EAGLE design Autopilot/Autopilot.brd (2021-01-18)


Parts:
LED1, LED2, LED3, LED4, LED5, LED6: LEDCHIPLED_1206; CHIPLED_1206
R1, R2, R3, R4, R5, R6: R-EU_R1206; R1206
SW1, SW2, SW3, SW4, SW5, SW6, SW7, SW8, SW9, SW10, SW11, SW12: 1571563-6; SW4_1437565-E
X1: 2514-; PAK100/2500-14

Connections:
5V: LED1.A, LED2.A, LED3.A, LED4.A, LED5.A, LED6.A, X1.7
GND: R1.1, R2.1, R3.1, R4.1, R5.1, R6.1, SW1.4, SW2.2, SW3.2, SW4.2, SW5.2, SW6.2, SW7.4, SW8.2, SW9.2, SW10.2, SW11.2, SW12.2, X1.8
unnamed: LED1.C, R1.2
unnamed: LED2.C, R2.2
unnamed: LED3.C, R3.2
unnamed: LED4.C, R4.2
unnamed: LED5.C, R5.2
unnamed: LED6.C, R6.2
unnamed: SW1.2, X1.9
unnamed: SW7.1, X1.5
unnamed: SW8.3, X1.3
unnamed: SW9.3, X1.1
unnamed: SW10.3, X1.2
unnamed: SW11.3, X1.4
unnamed: SW12.3, X1.6
unnamed: SW2.4, X1.11
unnamed: SW4.4, X1.14
unnamed: SW3.4, X1.13
unnamed: SW5.4, X1.12
unnamed: SW6.4, X1.10


Board: 2 copper layers, 34.0 x 81.0 mm, 25 parts (1 on the bottom side), 20 nets.

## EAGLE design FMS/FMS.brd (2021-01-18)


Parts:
LED1, LED2, LED3: LEDCHIPLED_1206; CHIPLED_1206
R1, R2, R3: R-EU_R1206; R1206
SW1, SW2, SW3, SW4, SW5, SW6: 1571563-6; SW4_1437565-E
X1: 2510-; PAK100/2500-10

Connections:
GND: R1.1, R2.1, R3.1, SW1.2, SW2.1, SW3.2, SW4.1, SW5.2, SW6.1, X1.5
unnamed: LED1.A, X1.3
unnamed: SW2.3, X1.1
unnamed: LED2.A, X1.2
unnamed: LED1.C, R3.2
unnamed: LED2.C, R2.2
unnamed: LED3.C, R1.2
unnamed: SW4.4, X1.4
unnamed: SW6.3, X1.6
unnamed: LED3.A, X1.7
unnamed: SW1.3, X1.8
unnamed: SW3.3, X1.10
unnamed: SW5.3, X1.9


Board: 2 copper layers, 35.0 x 50.0 mm, 13 parts (1 on the bottom side), 13 nets.

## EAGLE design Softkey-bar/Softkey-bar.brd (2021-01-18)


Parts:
JP1, JP2: PINHD-1X8; 1X08
LED1, LED2, LED3, LED4, LED5, LED6: LEDCHIPLED_1206; CHIPLED_1206
R1, R2, R3, R4, R5, R6: 470; R0805
SW1, SW2, SW3, SW4, SW5, SW6, SW7, SW8, SW9, SW10, SW11, SW12: 1571563-6; SW4_1437565-E

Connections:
5V: JP1.1, R1.1, R2.1, R3.1
5V2: JP2.1, R4.1, R5.1, R6.1
GND: JP1.8, LED1.C, LED2.C, LED3.C, SW1.4, SW2.4, SW3.4, SW4.4, SW5.4, SW6.4
GND2: JP2.8, LED4.C, LED5.C, LED6.C, SW7.4, SW8.4, SW9.4, SW10.4, SW11.4, SW12.4
unnamed: JP1.2, SW1.1
unnamed: JP1.3, SW2.1
unnamed: JP1.4, SW3.1
unnamed: JP1.5, SW4.2
unnamed: JP1.6, SW5.2
unnamed: JP1.7, SW6.2
unnamed: LED1.A, R1.2
unnamed: LED2.A, R2.2
unnamed: LED3.A, R3.2
unnamed: LED4.A, R4.2
unnamed: LED5.A, R5.2
unnamed: LED6.A, R6.2
unnamed: JP2.2, SW7.2
unnamed: JP2.3, SW8.2
unnamed: JP2.4, SW9.2
unnamed: JP2.5, SW10.2
unnamed: JP2.6, SW11.2
unnamed: JP2.7, SW12.2


Board: 2 copper layers, 220.0 x 15.0 mm, 26 parts (0 on the bottom side), 22 nets.

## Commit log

2021-01-18 Initial release.
    [Audio panel Embedded Mega breakout.brd, Audio panel Embedded Mega breakout.sch, Audio panel board.brd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]
2021-01-18 Changed drill size to 2.05mm, moved drills in AP board
    [Autopilot.brd, FMS.brd]
2021-01-18 Added Audio Board G1000.png
2021-01-18 General clean-up
    [Flip-Flop.brd, Flip-Flop.sch, Joystick board.brd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]
2021-01-19 Renamed panel to fit 12.1 inch panel
    [Audio panel board.brd, Audio panel board.sch]
2021-01-30 New Audio Panel
    [Audio panel board for 10.4 inch panel with ATMega.brd, Audio panel board for 10.4 inch panel with ATMega.sch, G1000 Arduino Breakout and MCPs.brd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]

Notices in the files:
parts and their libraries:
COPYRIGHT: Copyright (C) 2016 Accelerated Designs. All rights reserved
